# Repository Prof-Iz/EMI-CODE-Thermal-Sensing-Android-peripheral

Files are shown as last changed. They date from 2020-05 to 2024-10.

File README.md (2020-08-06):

# DISCLAIMER | Referencing
This is a work in progress!! Some code may have errors and is purely for my own personal tracking. Eventually if the code works and you are able to use it, by all means please do ;) but remember to **reference my code** to *avoid **plagiarism** issues*<br>
***Ibrahim Izdhan**, 1001852671, UCSI University, Electrical and Electronics Engineering*<br><br>
# EMI CODE Thermal Sensing Android peripheral
 Code repository for EMI Project May Sem Y2 Engineering<br>

Repository contains 4 folders
<ol>Android Code</ol>
<ol>Arduino Code</ol>
<ol>CAD Files</ol>
<ol>PCB Gerber Files</ol>

## Arduino Code
The project in question requires the Arduino to take in data from 2 sensor modules - a thermal sensing module and an ALS distance measuring module. Code would collect the data and then process it before passing data through connected serial to an accompanyng Android device. <br>

### Specifics of Data Processing on the Arduino

#### AP3216 Proximity Sensor (CJMCU - 3216)
The proximity sensor used in the project is a CJMCU IR and Light based proximity sensor. The sensor was programmed using the library by **Wollewad**
https://github.com/wollewald/AP3216_WE and tweaked for single pulse detection mode of proximity following the instructions on his repo. The values received for proximity are compared in a conditional that was calibrated for my specific sensor and if it was within threshold values (**distance of roughly 2 - 4 cm**) from forehead the reading from the thermal sensor is triggered - else the Arduino returns **0** in the serial indicating that the forehead is not at an optimal distance. <br>

#### MLX90614 Thermal Sensor (GY90614)
Once the thermal sensor is triggered, the **getObjectTemperatureC** method is invoked for the mlx object and it returns the temperature of the object. if it is between a validated range the Arduino prints the temperature to 1 dp to the Serial - else 0 is returned to indicate erroneous range for a human.
The code uses the **Adafruit Library for the Module** https://github.com/adafruit/Adafruit-MLX90614-Library to initialise the object and invoke the methods.

## Android Code
The Android app was built with Flutter and coded in Android Studio. The USB portion of the code is based on a flutter port of **felHR85**'s UsbSerial for Android https://github.com/felHR85/UsbSerial - which was found on pub.dev - provided by **Bessem.dev** https://pub.dev/packages/usb_serial. The example code was tweaked to make the phone connect to the first device input into the serial port and only displays the immediate serial data (*it was a list in the example*)

## 3D PRINTING
The CAD files of the Casing design can be found in the **CAD FILES** folder. CAD modelling by *Choy Juen Jet: Electrical and Electronics Engineering, **UCSI University***

## PCB Gerber Files
The files containing the schematic of our project's PCB is located inside the **PCB Gerber Files** folder. The PCB was designed by *Low Wai Sing: Electrical and Electronics Engineering, **UCSI University***

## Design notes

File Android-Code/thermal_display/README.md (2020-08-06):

# thermaldisplay

Supporting Android Application for the EMI project

## Warning
The usb serial library that is used proved to have some issues with Arduino Nano devices using the CH340 interface. The serial communication was unable to run in any mode besides the **release** version of the built APK, for the Arduino Nano and some older Arduino Boards. However, for our porject we used the **Seeeduino Xiao** which did not present these errors, despite running at the same settings for a Nano.

The **http** library that is used with this project to send a **GET** request to the Google Sheets Web App did not work properly with the release verson of the app, thus we had to use the Debug version with the larger binary footprint.

## Repositories/Packages Used
The Repositories/Packages that have been used for this project are noted below.
**usb_serial: ^0.2.4**
The package is used to establish serial connection with any connected devices and the android phone.
Documentation: https://pub.dev/packages/usb_serial

**maps_launcher : ^1.2.0**
The package provides a quick method to launch any maps software installed on your android phone with a specific search query.
Documentation: https://pub.dev/packages/maps_launcher

**path_provider : ^1.6.11**
This package provides commonly used locations on the filesystem. Supports iOS, Android, Linux and MacOS. Not all methods are supported on all platforms.
Documentation: https://pub.dev/packages/path_provider

**audioplayers: ^0.15.1**
This package is used in conjunction with path_provider to play audio files to alert the fever status before temperature is read out.
Documentation: https://pub.dev/packages/audioplayers

**flutter_tts: ^1.2.3**
This package is used to convert text (temperature value) into speech, which will be read out in your program.
Documentation: https://pub.dev/packages/flutter_tts

**flutter_barcode_scanner: ^1.0.1**
This package is to scan and return QR codes data before sending it to the GOOGLE SHEETS DATABASE using http.
Documentation: https://pub.dev/packages/flutter_barcode_scanner

**http:**
This package facilitates the GET request to store the data of individuals with a fever into a GOOGLE SHEETS, which is deployed as a Web App.
Documentation: https://pub.dev/packages/http

<br>
## Flow charts
Flow charts of how the data is roughly processed is given in the **FLOWCHARTS** Folder

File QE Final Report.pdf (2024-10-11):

# FINAL REPORT

# PHONE BASED

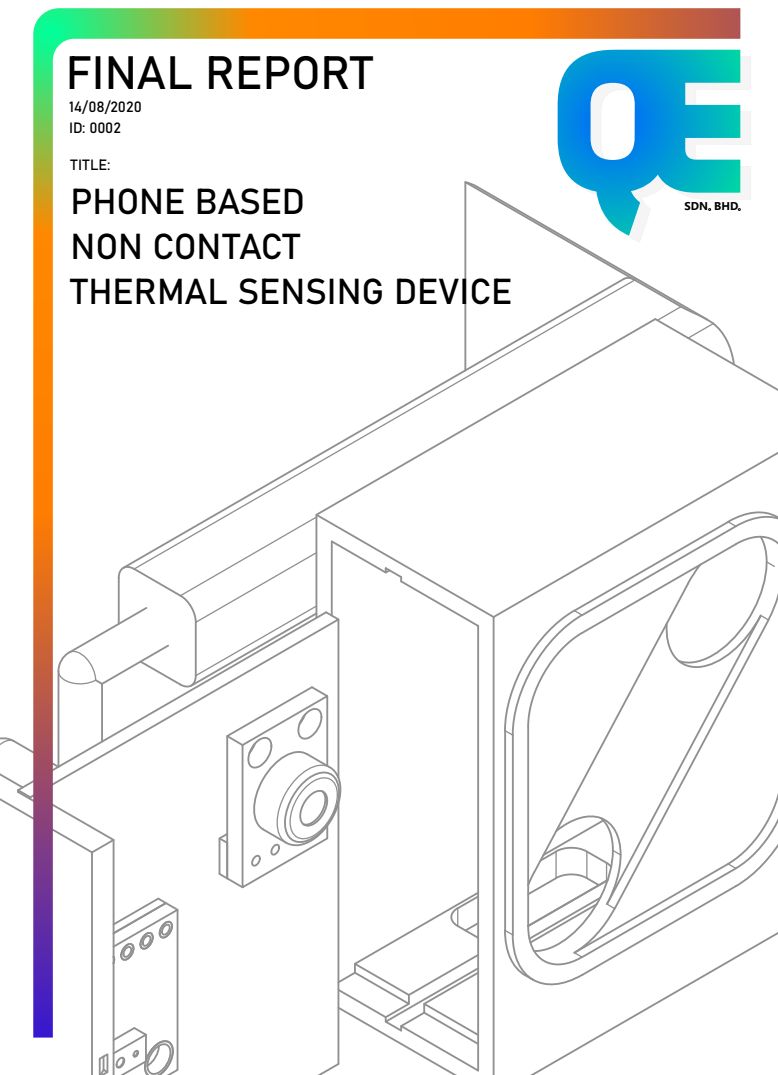
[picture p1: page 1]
SDN. BHD.; TITLE:

NON CONTACT
THERMAL SENSING DEVICE

Non-Contact Phone Thermometer

1

## Contents

2

3

## 1. Introduction

## 1.1. Team Members

Project Engineer: Lim Yee Teng

Software Engineer: Ibrahim Izdhan

CAD Engineer: Choy Jun Juet

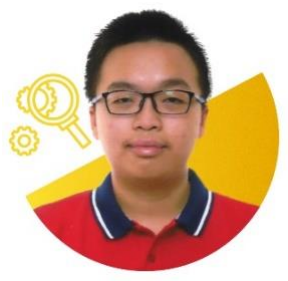
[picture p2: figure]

Test Engineer: Wong Wai Kiat

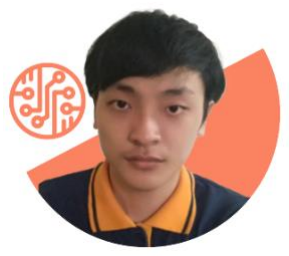
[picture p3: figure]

PCB Engineer: Low Wai Sing

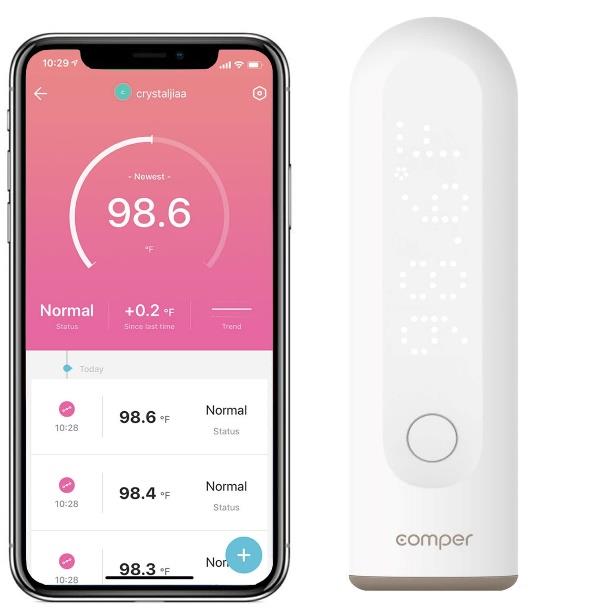
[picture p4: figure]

4

## 1.2. Market Research / Existing Product

The need for thermal screening devices has increased in demand in the wake of the recent Covid-19

pandemic due to its ability to aid frontline workers and governments in determining early signs of infection at

entry screening points [1]. The need for effective thermal monitoring solution has caused an untimely gap in

the supply and demand of conventional devices to achieve this solution – either causing existing solutions to

become unable to deliver or causing spike in prices [2].

One of the market similar smartphone based non-contact thermometers is the thermometer produced by

‘Comper’. Its application is likely used in the medical field. Its measurement method is through infrared ray to

measure the body temperature of people by pointing their forehead. It can be connected to the phone through

Bluetooth to show the value of temperature on the phone. Its temperature range is between 32 oC (89.6 oF)

and 43 oC (109.4 oF). The Comper Smart Infrared Thermometer is designed to read the body temperature

as easy as possible. Besides, their Comper Health App can visualize the body temperature ranges and

trends. The smart infrared thermometer can provide maximum precision with results that are accurate within

0.2 oC and it also can provide results in less than a second. Other than that, Comper Smart Infrared

Thermometer also includes a convenient smart app with features like sharable readings and real time

analytics, and it also supports an unlimited number of users. The thermometer can automatically record all

the temperature and save them to the app for tracking purposes.

Figure 1 Similar Existing Product - Comper Thermal Screening Device [3]

5

## 1.3. Problem Statement

The increase in Covid-19 cases across the country has sparked a need for proper, easily accessible and

cheap screening procedures to be developed in order to accommodate the rising demand for such devices

in places of high traffic. Such a device should be able to screen for fevers, which is a common symptom of

Covid-19, without implicating the persons using the screening device, via non-contact measurement of body

temperature. The device should be easy to operate and should be powered with a power source that is readily

available for most individuals – with clear indication of remaining power status and ability to recharge.

## 1.4. Objective

To develop a cheap Arduino Based non-contact thermometer that interfaces with the user’s phone to provide

clear and precise (to within an acceptable margin of error) temperature of a person being screened. The

device should be powered by the phone’s serial port as well as provide data to the phone via the port to be

processed and displayed on the phone.

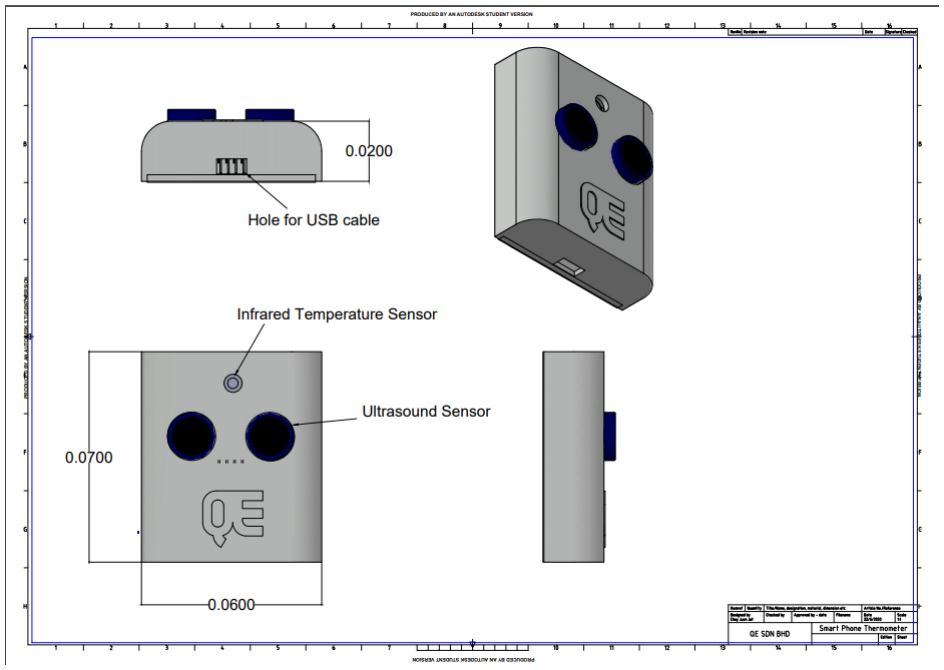
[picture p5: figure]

6

## 2. Methodology

## 2.1. Draft of Product in Proposal

The casing of the design will be

attached to the back of the smart

phone via a simple clamping

mechanism found in most cheap

phone holders – allowing for the

placement of the thermal device to

be agnostic to the dimensions of the

phone. | This | draft | outlook

implements the Ultrasound sensor

to detect proximity of the forehead

from the sensor – the effectiveness

of detection and option to switch to

IR proximity will be tested by test

engineer and the design will be

further revised if necessary.

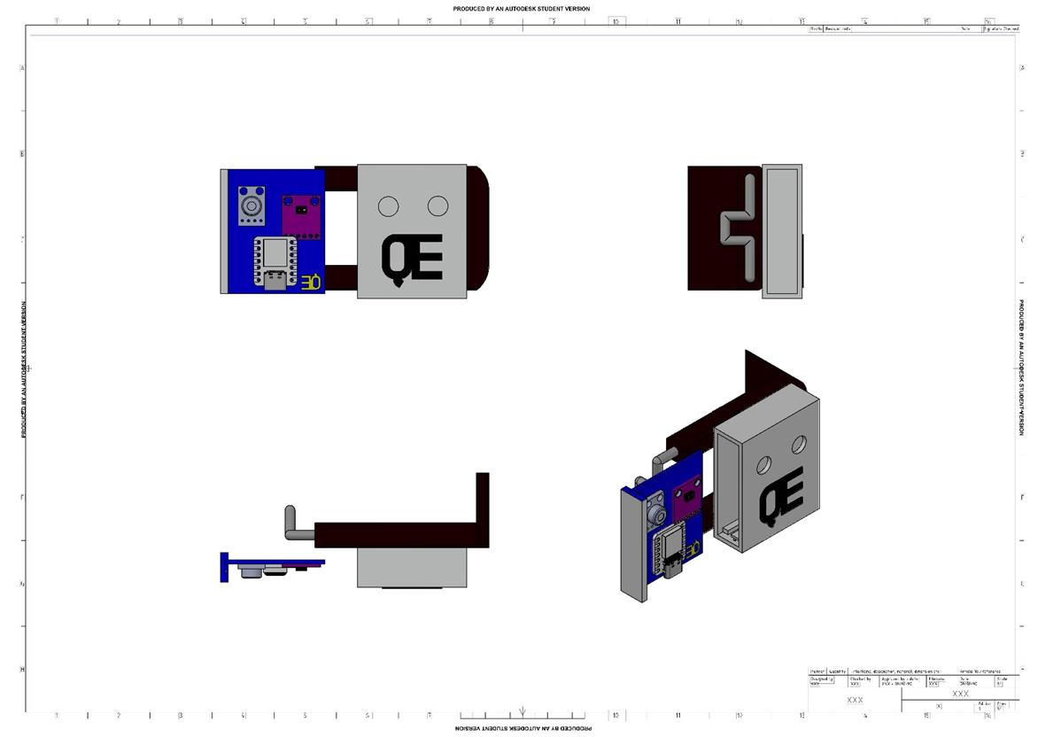
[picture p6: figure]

7

## 2.2. Changed Design due to Hardware Change (1)

The design is based on the PCB

board we first drafted. The PCB

board has 3 important components

which is the Seeeduino Xiao,

temperature | sensor | and | the

proximity sensor. There are 3 holes

designed specifically for these

components. The first one is a

rectangular hole with round edges

at the bottom of the casing which

enables the USB cable connection

with the Seeeduino. The second

and third hole in front of the casing

is for the temperature sensor and

proximity sensor.

Figure 2 Initial Design of Device

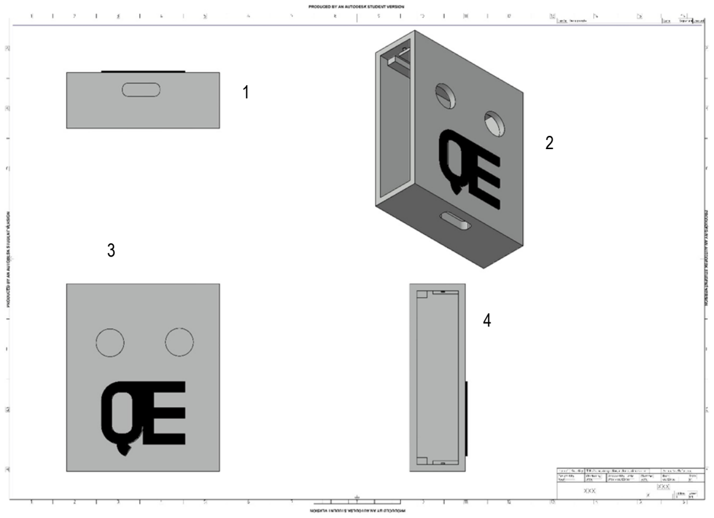
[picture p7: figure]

8

The holes are needed for the temperature

sensor and proximity sensor since the

casing will get in the way of the sensors if

the holes are not there. The holes are

aligned to make the casing tidier. The

logo of our company “QE” is added below

the 2 holes in front of the casing to make

it more aesthetic.

Features:

The hole at the bottom as shown in 1 is

used to connect the USB cable.

The 2 holes in front of the casing as

shown in 3 is for the temperature sensor

and proximity sensor.

The side as shown in 2 and 4 have a

place holder for the PCB board. The PCB

will be attached to the cover at the side

and then slide into the casing.

Figure 3 Initial Design without components nor attached support

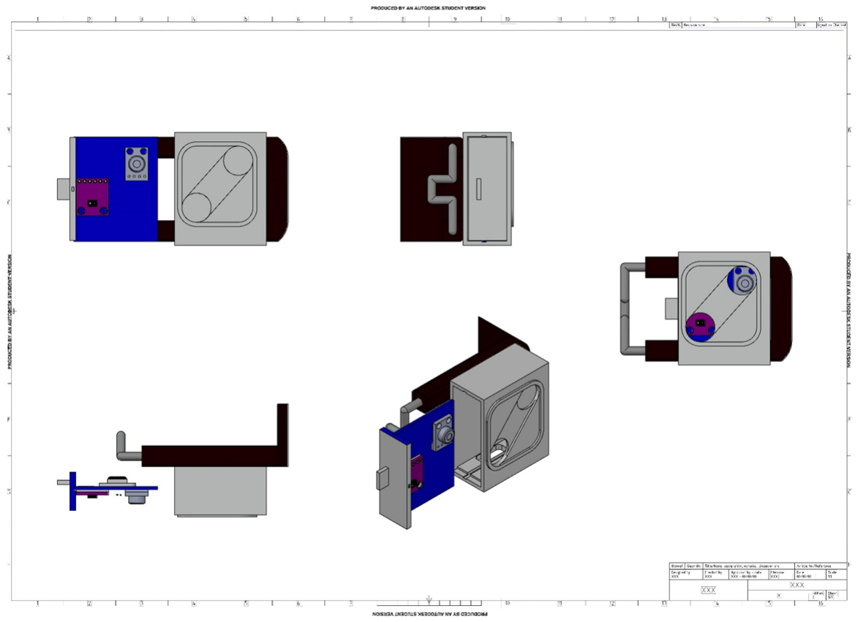
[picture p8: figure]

9

## 2.3. Final Casing Design after Design Restrictions

When we solder the components onto the

PCB, we had some problems with the

placement of the components. To resolve

the problem, the holes for the

components are moved to their

respective components to make the

device work. The new design is based on

the first design with the sliding PCB

mechanism and holes for sensors. A

locking mechanism is added because the

previous design has a problem with the

slide sliding off when in use. A small

extension piece at the side casing is there

because the side casing couldn’t be open

once the casing is closed. The small

piece at the side making sure the casing

can be opened after that. The round edge

rectangular hole for the USB

Figure 4 Final Casing with Support

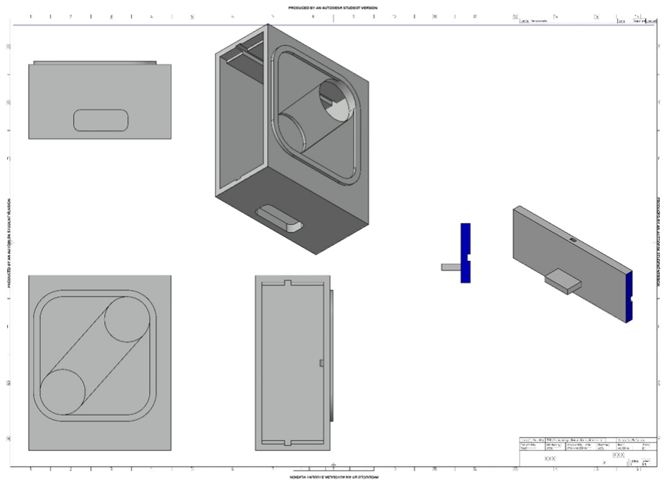
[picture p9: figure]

10

USB didn’t change much except for the

position and the increased size. The

holes for the sensors are also made

bigger to make sure there is no

interference from the casing. Since the

holes are repositioned, the “QE” logo was

removed as there is not enough space for

it. To replace the logo design, a bridge

like structure is made between the holes

where it makes the holes look like its

connected. There is also a square with

round edges around the holes to make it

look tidy rather than holes randomly

placed on the casing.

Features different with second draft:

Hole placement changed to reflect the

PCB.

Side Mounted wall thinner to allow easier

insertion of PCB into case.

Figure 5 Final Casing Design without supports and PCB

11

## 2.4. Proposed Hardware

Arduino Nano | Serve as the Microcontroller to receive data from the thermal sensor (via I2C) as
| well as the ultrasound sensor (via digital pins) and send the data through serial to
| the connected android device. The Arduino will route power supplied to it by the
| phone through its 5V (out) pin to supply power to the attached sensors as well. Any
| intermediate data processing to be done before transmission of data to the phone
| will also be done on the Arduino
MLX90614 Thermal Sensor (GY90614) | The thermal sensor (PCB module) used to detect temperature values. The libraries
| of the sensor are provided by the manufacturer and thus can be used to detect
| temperature at 2- 5 cm with minute manual tuning required in software.
HC-SR04 Ultrasound Sensor Module | The Ultra sound sensor will be used to ensure that the distance from the
| temperature sensor to the forehead of the individual is within the effective range of
| 2 – 5 cm. Processing of distance done within Arduino

## 2.5. Changed Hardware from Proposal Stage

Seeeduino Xiao | Replaces the Arduino Nano as it has a smaller from factor. It is still coded in Arduino
| thus poses no additional development requirements.
AP3216 Proximity Sensor (CJMCU - 3216) | Replaces the HC-SR04 as it is more compact and due to the sequential nature of
| both reading distance and taking temperature (by the temperature sensor), no
| interference is expected due to delay inserted in software.

12

## 2.6. Proposed Software

CAD DESIGN | The proposed software for CAD design of the casing of the non-contact thermometer is Auto CAD due to the simple nature of the casing design (no mechanically moving components) as well as prior experience with Auto CAD
PCB DESIGN | The proposed software for PCB Design is EasyEDA due to its simple UI and low learning curve. In addition, the said software supports placing order for custom made PCBs through vendors such as JLC PCB (easy output to Gerber file)
App Development (Android) | The proposed software for developing the phone interface to be used with the non- contact thermometer is Android Studio as it will allow the creation of a highly customizable and free (in terms of subscriptions to be paid for the use of said app or specific allowances required for the design of the app) android application that can be provided free of charge alongside the device. Android Studio allows for virtual debugging, though this will not be as useful for a serial-based application, the layout can be tested before being uploaded onto a real test device
Arduino Coding | The base Arduino IDE is the only available method and will be used to code the Arduino Nano that will be used in the non-contact thermometer

## 2.7. Changed Software from Proposal Stage

App Development | Production switched from JAVA to using the Flutter framework by google, which implements the use of the DART programming language.
3D Printing | Since it was decided to 3D print the casing for the thermal sensing device, Ultimaker Cura was used as it is a free and eeasy to use 3D printing/splicing solution

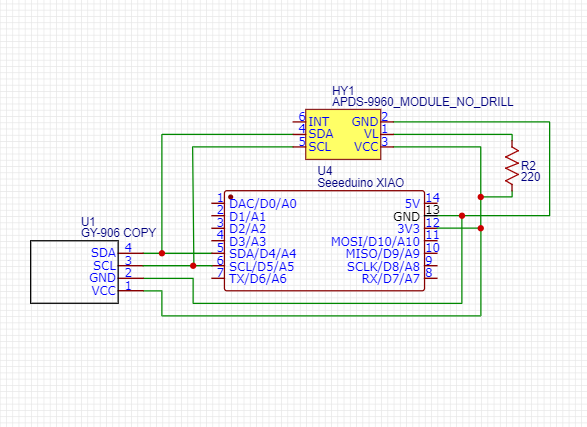
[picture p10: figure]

13

## 3. Circuit Design

Figure 6 Circuit Schematic of the project

The operational voltage of both the GY-906 and the AP3216 Proximity Sensor is between 3.3 – 5 V, thus the

lower option was preferred for safety of the components. Both of these sensors are designed to communicate

using the I²C protocol and as such have been connected in a manner that their SCL (Clock) and their SDA

(Data) are interconnected with each other. A 220-ohm resistor is used to bias the IR blasting mechanism in

the AP3216 Proximity Sensor. All grounds in this system are common (Seeeduino) and are interconnected

together.

The circuit as seen in Figure 6 was designed in EasyEDA to streamline the PCB manufacturing process later

on. The schematic connections were chosen from the EDA library and then compared to ensure that the

models were the same. As noticeable in Figure 6, the model for AP3216 Proximity Sensor, is used

interchangeably with the APDS9960 as the connection schematic is the same.

14

## 4. Breadboard Testing

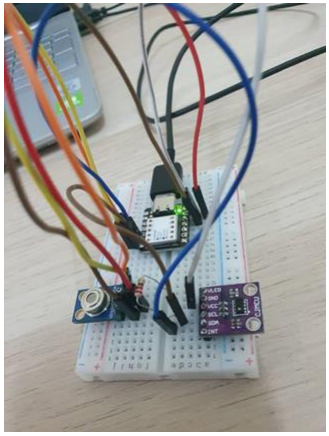
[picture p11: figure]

Figure 7 Breadboard placement of components

Before doing the breadboard testing, the MLX90614

thermal sensor and proximity sensor were soldered

with the pins provided to ensure that they have good

connection with the breadboard while testing on it –

so that the signal passed using I2C is delivered

properly.

Next, the code written by software engineer was

transmitted to the Seeeduino XIAO for the test

engineer to test the functionality of thermal sensor

and proximity sensor individually using the standard

test code provided by the manufacturer. Afterwards,

the test engineer placed all the components on the

breadboard based on the circuit designed by the

PCB engineer as shown in Figure 7 and check

whether the components were connected correctly

to prevent short circuit. In our first testing on

breadboard, we did not get the results that we

wanted. Then, after further testing, the test

engineer figures out that it is the problem of

breadboard and replaced it with another new

breadboard. After replacing the breadboard, we

observe the results that we wanted. This means that

all the components are in good condition and the

circuit connection is correct. Afterwards, the tested

components were handed to the software engineer

for further calibration and tuning.

## 5. PCB Design

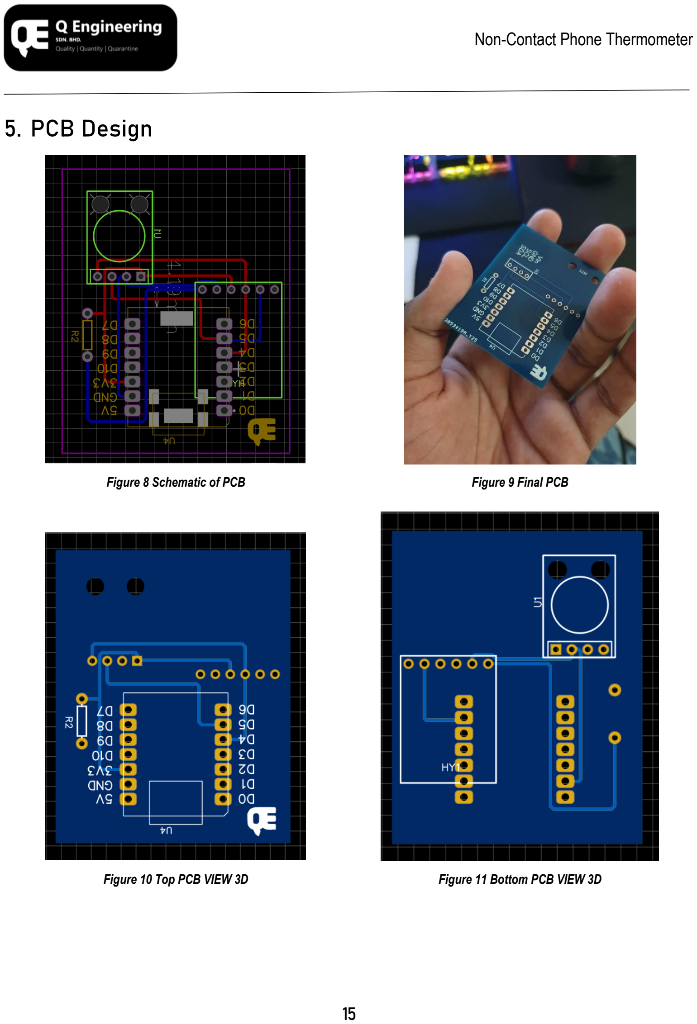
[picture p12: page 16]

15

Figure 8 Schematic of PCB | Figure 9 Final PCB
Figure 10 Top PCB VIEW 3D | Figure 11 Bottom PCB VIEW 3D

16

PROCEDURE:

1. After designing the circuit, converted it to PCB and the footprint of the electronic parts were checked
2. Set the PCB board outline as diameter equal to (50mm*40mm).
3. Dragged all the electronic parts at the default position inside the PCB board.
4. Changed the proximity sensor and infrared thermometer sensor from top silk layer to bottom silk

layer.

5. Set the width of trace as 20 mil at the setting and start connecting the components. Changed to trace

to bottom layer when the trace overlaps each other.

6. Selected image at ‘PCB tools’ to insert our company logo at top silk layer of our PCB design.
7. After finishing and saving the PCB design, click the ‘Design Manager’ to check for any errors
8. Gerber file for our PCB design was then generated once everything was set up correctly and ordered

our PCB through JLCPCB.

When converting the circuit design to PCB, ensure all the components have the correct footprint with the real

components that are used. For the connection of traces in the PCB, avoid using 90-degree trace angles, opt

for 45 degrees as the edge of the 90 degrees tracks will be etched smaller than the trace width set by designer

or those tracks will not be fully etched and might lead to a short circuit. For the ideal PCB design, the turning

point of each track should be curved but due to limitation, we used the smaller 45 degrees gaps. Next, enough

space should be left between all the tracks and the components so as to avoid overlapping as the PCB

manufacturing process might not be entirely precise. As we know, the higher the resistance, the lower the

power dissipated as the resistance is inversely proportional with current, and current powered by two is

directly proportional to power consumption. Last but not least, PCB design should always be printed on a

blank paper to double check whether the footprint is exactly similar to the parts that are being used to ensure

that the specific component matches with the footprint in EasyEDA.

17

## 6. Software Development

## 6.1. Android App Draft Plan

Illustrated below is the draft plan of the layouts (views¹
) that comprise the accompanying android application to be used with the thermal sensing

device. Design is subject to change based on further debugging or usage testing.

View when serial device is

properly transmitting data

and temperature is within

accepted range

View when serial device

is disconnected or there

is an issue with data

received

View when the data

received indicates that the

forehead is too far from

the optimal range

View when the

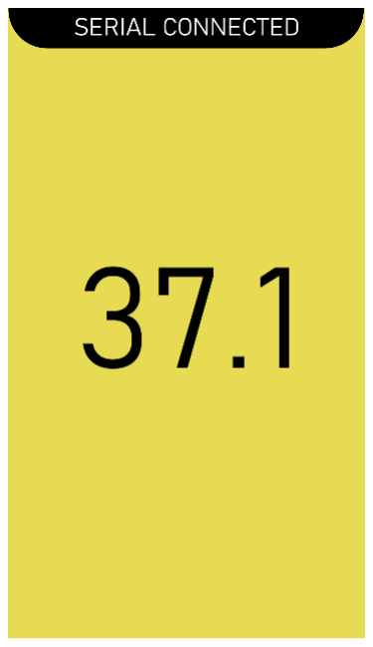
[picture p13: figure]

temperature is close to

the upper threshold for a

fever

View when fever detected

– button to view hospitals

on maps (google

extension)

1 Android applications are comprised of “views” that contain fundamental elements such as images, text and other placeholders – whose attributes can be updated via functions

18

## 6.2. Android App Finalized Widgets

The draft design of our application was designed with the software intended to be coded in JAVA. However, during production the team decided that

Flutter would be a more interactive solution to designing the app hence the design was slightly altered while maintaining key design features from the

previous design and implementing additional features which will be discussed in detail in the following sections.

Initial Startup Screen of

Application, Seeeduino

not detected thus showing

Disconnected

Status shows connected

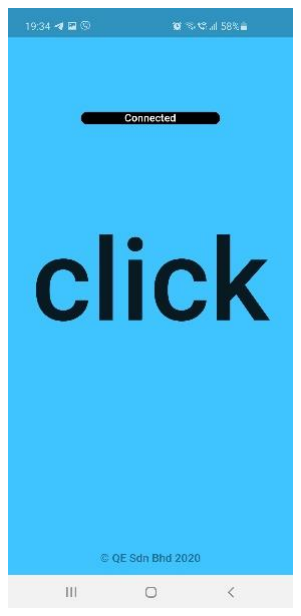
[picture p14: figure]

but the request to get

temperature reading not

set

Screen that shows

temperature received if it

is within a non-fever

region. Color changes.

When fever is detected a

button appears with more

options as seen in the

bottom right.

More options screen once

fever detected, to scan QR

and upload details to

server, call Hospital

19

## 6.3. Main Screens in Detail

1 – The Serial Connection Status between the

Seeeduino and the Phone. It will update the

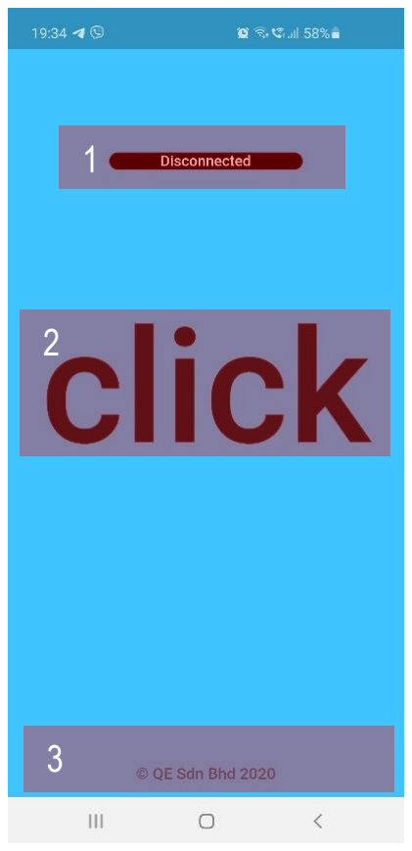
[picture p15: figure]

message | when | the | Seeeduino | is

connected/disconnected and will also update if the

Android program detects if there are any problems

with the connection, such that a device is connected

but data is unable to send properly.

2 – The entire region serves as a button which

initiates the requestTemperature() function, which

will prompt the Seeeduino to send data over to the

phone.

3 – If the user clicks this region they will be taken to

a widget(page in Flutter) where the information of

the compay is displayed and they may contact us

via Instagram.

These 3 Regions are present in all screens

(besides the QR scanning page and company info

page)– and serve the same function.

20

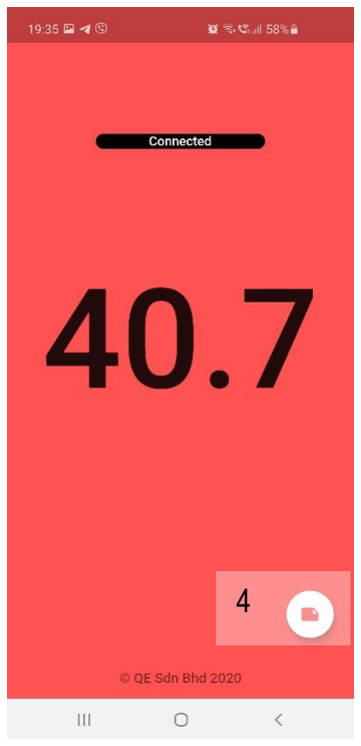
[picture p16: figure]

4 – Once the average temperature taken over 3

successful consecutive readings average out to be

greater than the standard fever temperature (37.5o

C), the region is made active. Clicking on the button

in this region will direct the users to a widget (screen

below) where they will be able to deal with such

cases more effectively.

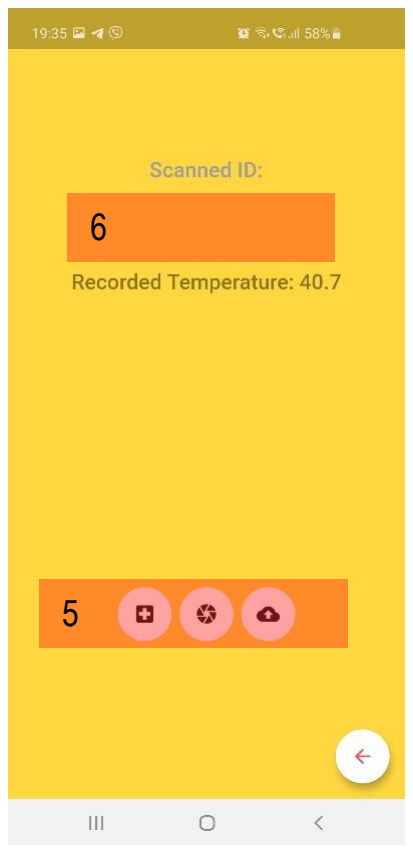
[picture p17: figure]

5 – This region consists of 3 buttons with 3 distinct

functions. From the left, the button opens up any

mapping software installed on your device such as

google maps and automatically searches for

hospitals nearby. The second button, when pressed

opens a scanning window where the user can scan

the ID of the affected Employee. This data is

automatically displayed on (6) so that they may

double check the reading. The last button in this row

automatically updates the data of the ID, as well as

the temperature recorded to a Google Sheets

database that the company HR may keep track of –

no manual entry required.

21

## 6.4. Installation of IDEs

ARDUINO IDE

The Arduino IDE can be installed through the windows store or following instructions located at the

official Arduino Website https://www.arduino.cc/en/main/software. The Seeeduino board used

should be enabled in the IDE by following the instructions found at the official Seeeduino website

https://wiki.seeedstudio.com/Seeed_Arduino_Boards/

ANDROID STUDIO (FLUTTER)

Android Studio can be installed using the link https://developer.android.com/studio/install. Once the

IDE has been installed, enable Flutter development on Android Studio using the instructions on the

Flutter website https://flutter.dev/docs/get-started/editor.

In your Flutter project, inside android > app > build.gradle set the minSdkVersion 21 so that the QR

code scanning features work.

## 6.5. Arduino Dependencies

The project in question requires the Arduino to take in data from 2 sensor modules - a thermal sensing module

and an ALS distance measuring module. Code would collect the data and then process it before passing

data through connected serial to an accompanying Android device.

AP3216 Proximity Sensor (CJMCU - 3216)

The proximity sensor used in the project is a CJMCU IR and Light-based proximity sensor. The

sensor was programmed using the library by Wollewad, which can be accessed

at https://github.com/wollewald/AP3216_WE , and tweaked for single pulse detection mode of

proximity following the instructions on his repo. The values received for proximity are compared in a

conditional that was calibrated for our specific sensor and if it was within threshold values (distance

22

of roughly 2 - 4 cm) from forehead the reading from the thermal sensor is triggered - else the

Arduino returns 0 in the serial indicating that the forehead is not at an optimal distance.

MLX90614 Thermal Sensor (GY90614)

Once the thermal sensor is triggered, the getObjectTemperatureC method is invoked for the mlx

object and it returns the temperature of the object. if it is between a validated range the Arduino prints

the temperature to 1 dp to the Serial - else 0 is returned to indicate erroneous range for a human.

The code uses the Adafruit Library for the Module https://github.com/adafruit/Adafruit-MLX90614-

Library (https://github.com/adafruit/Adafruit-MLX90614-Library) to initialize the object and invoke the methods.

## 6.6. Flutter Dependencies

The dependencies to be placed in the pubspec.yaml file in your Flutter project are bolded below with a short

description of what each package does.

usb_serial: ^0.2.4

The package is used to establish serial connection with any connected devices and the android

phone.

Documentation: https://pub.dev/packages/usb_serial

maps_launcher : ^1.2.0

The package provides a quick method to launch any maps software installed on your android phone

with a specific search query.

Documentation: https://pub.dev/packages/maps_launcher

path_provider : ^1.6.11

This package provides commonly used locations on the filesystem. Supports iOS, Android, Linux

and MacOS. Not all methods are supported on all platforms.

Documentation: https://pub.dev/packages/path_provider

23

audioplayers: ^0.15.1

This package is used in conjunction with path_provider to play audio files to alert the fever status

before temperature is read out.

Documentation: https://pub.dev/packages/audioplayers

flutter_tts: ^1.2.3

This package is used to convert text (temperature value) into speech, which will be read out in your

program.

Documentation: https://pub.dev/packages/flutter_tts

flutter_barcode_scanner: ^1.0.1

This package is to scan and return QR codes data before sending it to the GOOGLE SHEETS

DATABASE using http.

Documentation: https://pub.dev/packages/flutter_barcode_scanner

http:

This package facilitates the GET request to store the data of individuals with a fever into a GOOGLE

SHEETS, which is deployed as a Web App.

Documentation: https://pub.dev/packages/http

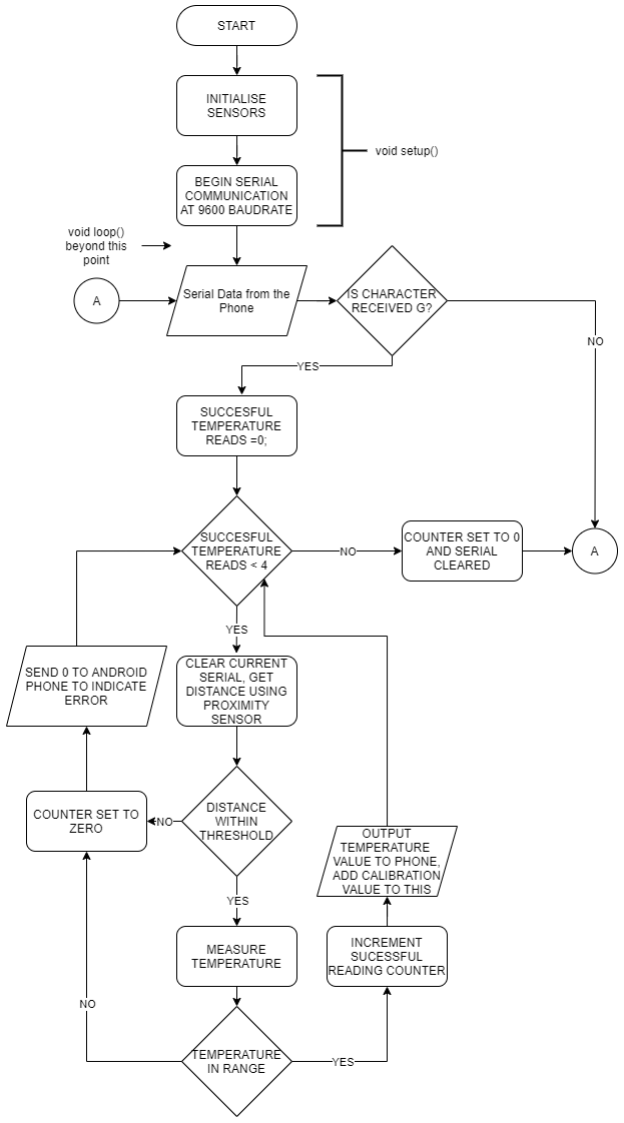
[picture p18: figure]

24

## 6.7. Flow Chart Seeeduino (Arduino)

Figure 12 Flow Chart of Arduino Code

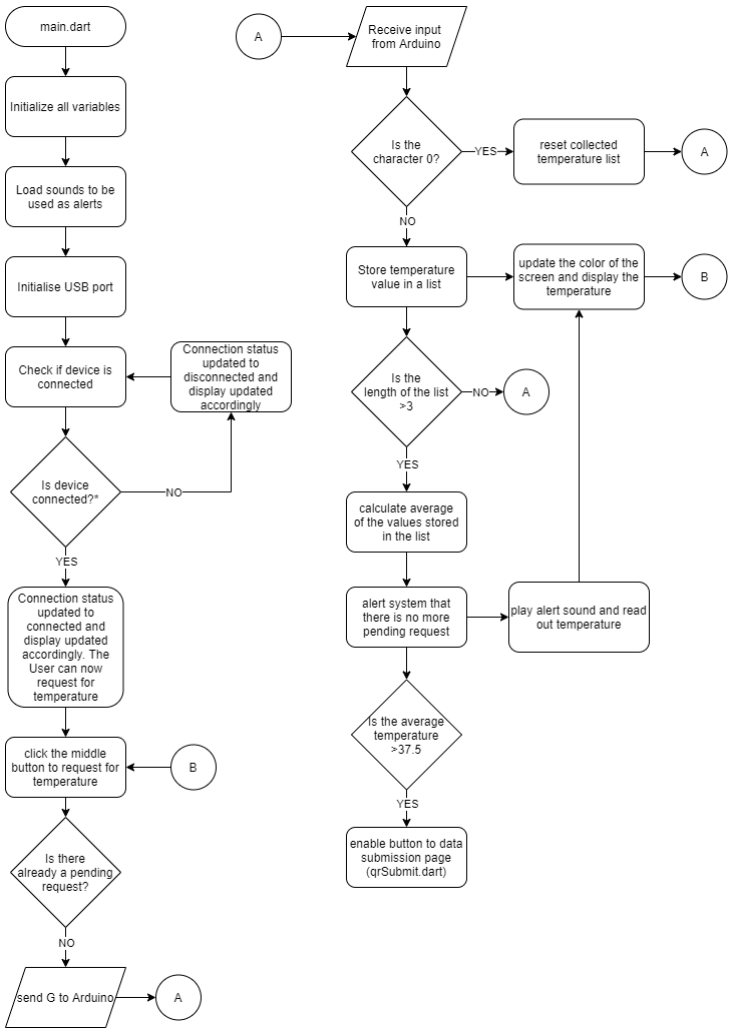
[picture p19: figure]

25

## 6.8. Flow Chart Android App

Some actions are always running in the background hence it is indicated with a *.

Figure 13 Flow chart of home screen

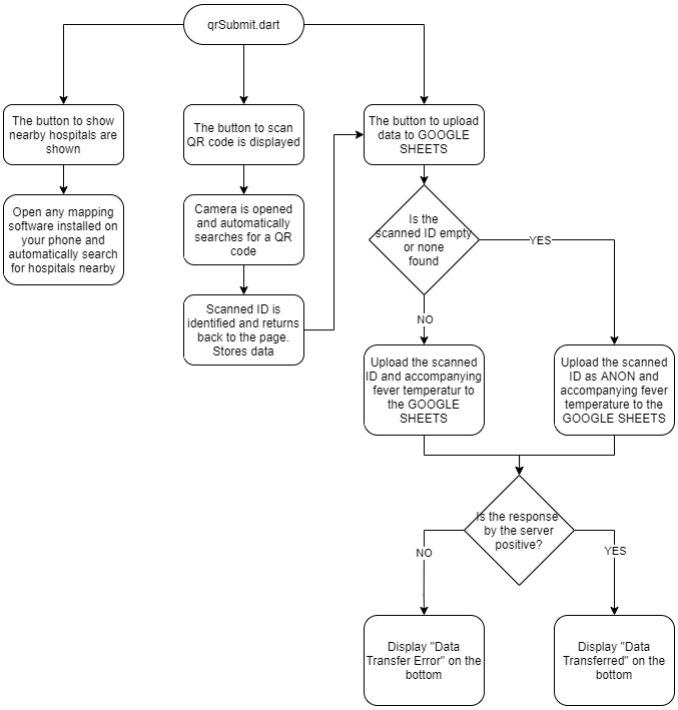
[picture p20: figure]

26

Figure 14 Flow Chart of Fever response page

27

## 6.9. Explanation of Key Functions (Arduino)

getProximityArduino() This function when called first sets the proximity sensor to a single pulse

mode. Then after a delay of roughly 0.6 seconds, it measures the distance

using the proximity sensor. If the retrieved distance value is between a

range of 1000 of 40 (which is roughly between 2-4 cm), the function goes

to getTemperature(). If the distance is greater the counter of successful

readings and sends 0 to the Android phone as mentioned in Figure 12.

getTemperature() Read the temperature and store it. Checks if temperature is between 10

and 50 degree Celsius and if its is out of this range, resets the counter of

successful readings and sends 0 to the Android phone as mentioned in

Figure 12. If it is within the accepted range the temperature that was

recorded to the Android Phone.

## 6.10. Explanation of Key Functions (Android)

main.dart – HomeScreen

_speak() This function makes your code read out the given text. Which in our

case, includes the temperature displayed on the Screen (Final

Average Temperature).

playSoundFever() and

playSoundNormal()

These Functions play a warning sound (playSoundFever()) when

the temperature of the user averages out to be more than 37.5, or

an okay sound effect (playSoundNormal()) when the temperature is

lower than 37.5. These functions are triggered whenever the final

average temperature is calculated.

28

_loadSounds() Prepare the sounds that are used in the above portion.

_connectTo(device) This function connects to the device passed into it and sets the app

so that it automatically updates the status of the connection and

once the data is received from the Arduino, it automatically updates

the display in the middle of the app.

_getPorts() This function runs when a device is connected into the Android

phone, and checks whether it can establish a communication to the

device using the above function.

requestTemperature() This function sends a letter G to the Arduino triggering the Arduino

to start its reading process. This function is programmed in a way

so that it does not allow multiple requests – one request sent to the

Arduino at a time.

updateColorsAndOpacity() This function is run each time the phone receives a temperature

reading from the Arduino. It tries and takes 3 successful consecutive

readings from the Arduino and calculates the average. If this

calculation is interrupted by the 0 message from the Arduino, the

phone displays FAR to indicate that the value is false and repeats

the average procedure from scratch again. Once the average

temperature is calculated, appropriate sounds are played and the

color of the background changes. If a fever is detected, it allows the

user to navigate to another page (by showing a button) that would

allow them to store the temperature in a database, or search for

nearby medical assistance.

29

qrSubmit.dart – The screen that pops Up after you click the button to log temperature when fever

is detected

scanEmployeeID() This function opens the camera and allows you to scan QR codes.

Returns the QR code value and is displayed on the screen.

submitData() This function when invoked submits the data to the GOOGLE

SHEETS web app that will be created upon the request of the

company. For now it sends the scanned ID and the temperature that

was recorded to the web app in the URL inside the function.

_showSnackbar(String message) This function shows a little notification on the bottom of the app with

whatever message is passed into it. It is used inside submitData()

to show the status of the data upload.

## 7. Source Code and All Accompanying files

The source code of the project can be found at our software engineer’s GitHub account and is distributed

under the MIT License of fair usage. https://github.com/Prof-Iz/EMI-CODE-Thermal-Sensing-Android-

peripheral. (https://github.com/Prof-Iz/EMI-CODE-Thermal-Sensing-Android-peripheral) This source code further explains in detail of how the code works through comments. The GitHub

repository also contains the STL files of the CAD model for 3d printing as well as the Gerber files of the PCB.

If anyone wished to reproduce our results they may do so using the resources available at this repository.

## 8. Warning

Due to the nature of some dependencies having issues in Flutter, the app was built and is distributed in

Debug mode. It offers the same functionality as the release version of the app with the exception of the file

size being larger, though this does not pose much of a challenge as the max size is still approximately 50MB.

Since the components need to be soldered using a soldering iron onto the PCB, care must be taken to ensure

that the thermal sensor is not exposed to high heat during the soldering process.

## 9. Finished casing and Product

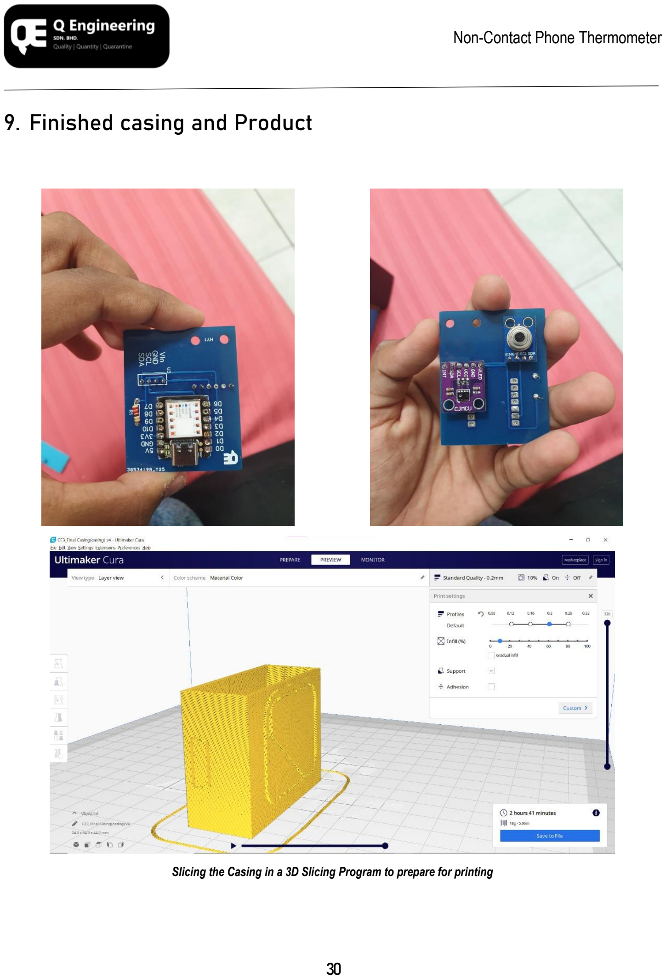
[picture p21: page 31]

30

Slicing the Casing in a 3D Slicing Program to prepare for printing

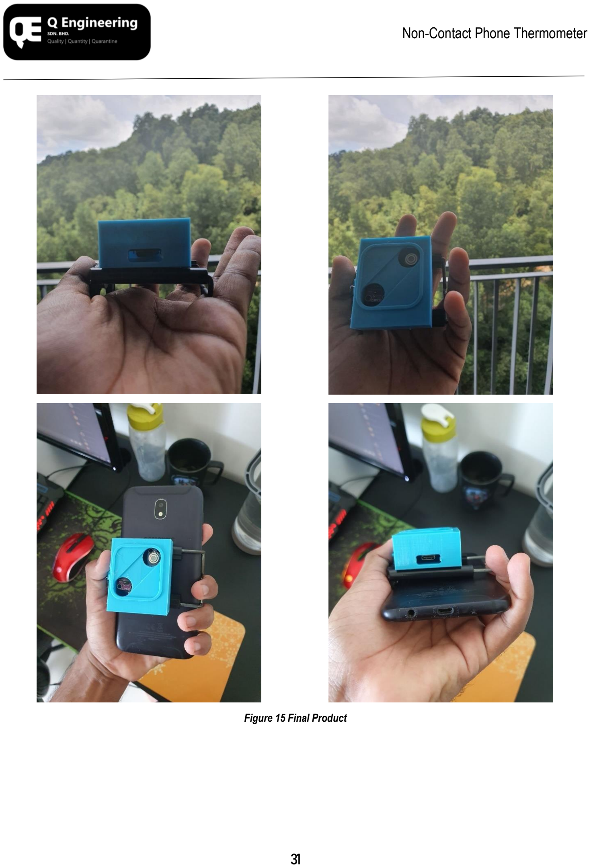
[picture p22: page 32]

31

Figure 15 Final Product

32

## 10.Costing

## 10.1. Projected Costing

Item | Approx. Unit Price | Quantity | Subtotal
MLX9061 GY-906 Module | MYR 100.00² | 1 | MYR 100.00
Arduino Uno | MYR 14.00 | 1 | MYR 14.00
Ultrasound Sensor Module HC-SR04 | MYR 5.00 | 1 | MYR 5.00
Casing | MYR 10.00 | 1 | MYR 10.00
PCB Manufacturing | MYR 20.00³ | 5 4 | MYR 20.00
| | Total | MYR 149.00

## 10.2. Actual Costing

Item | Approx. Unit Price | Quantity | Subtotal
MLX9061 GY-906 Module | MYR 132.00 | 1 | MYR 132.00
Seeeduino Xiao | MYR 34.90 | 1 | MYR 34.90
AP3216 Proximity Sensor | MYR 12.00 | 1 | MYR 12.00
Casing (3D print)⁵ | MYR 0.90 | 1 | MYR 0.90
PCB Manufacturing + Shipping | MYR 28.37 | 5 | MYR 28.37
| | Total | MYR 208.17

The high price in making of the functional prototype is mainly attributed to the inflated price of the MLX9061

GY-906 Module due to shortages in supply and increased demand due to the onset of COVID -19. This

sensor tends to retail as low as MYR 20 s thus we anticipate that with the increase of supply and decrease

2 Sensor price currently high due to increased demand during Covid-19 Peak season
3 Rough conversion from USD to MYR and approximation of shipping fees for 5 PCB
4 PCB printing service provides 5 PCBs as standard package – only one used per thermal device 5 Assuming 1kg reel at RM50

33

in demand stabilizes the price back to its pre COVID-19 levels, the price of the product will become more

affordable.

## 11. Special Thanks

TMOM Sdn Bhd and QE Sdn Bhd worked closely and shared development ideas regarding the software thus

we would like to express our gratitude to them.

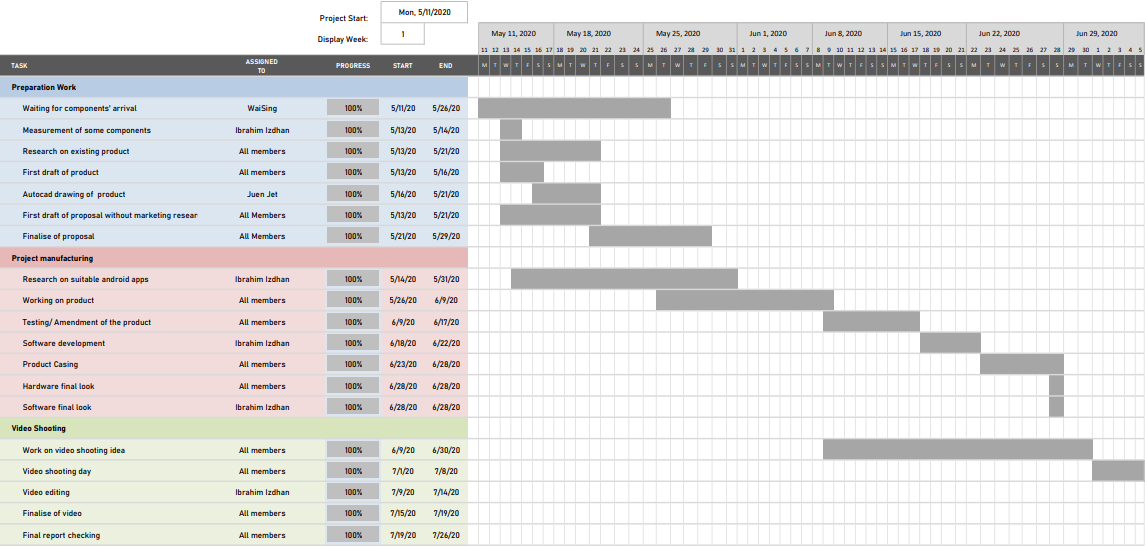
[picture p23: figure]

34

## 12.Project Schedule

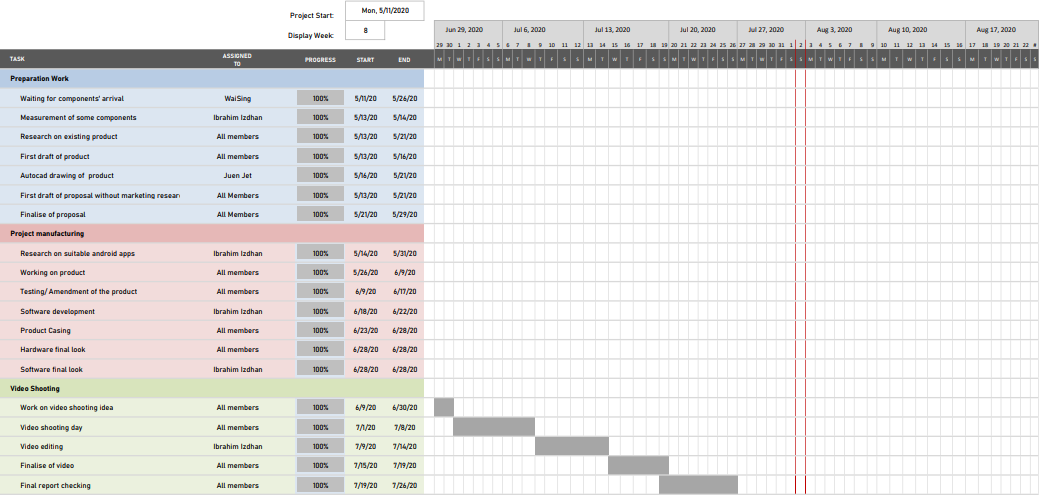
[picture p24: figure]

35

36

## 13.References

[1] WHO, "Updated WHO advice for international traffic in relation to the outbreak of the novel coronavirus

2019-nCoV," 2020. [Online]. Available: https://www.who.int/news-room/articles-detail/updated-who-

advice-for-international-traffic-in-relation-to-the-outbreak-of-the-novel-coronavirus-2019-ncov-24-jan/.

[2] J. Bogaisky, "Tech That Scans People For Fever In Big Demand Amid Coronavirus Crisis, Boosting
Wuhan | Company," | Forbes, | 2020. | [Online]. | Available:

https://www.forbes.com/sites/jeremybogaisky/2020/02/10/we-are-running-as-fast-as-we-can-

coronavirus-sparks-surge-in-demand-for-infrared-fever-detection-equipment/#191e675d60c9.

[3] Medical Expo, "MEDICAL THERMOMETER / INFRARED / NON-CONTACT / FOREHEAD," [Online].

[Accessed 2020].

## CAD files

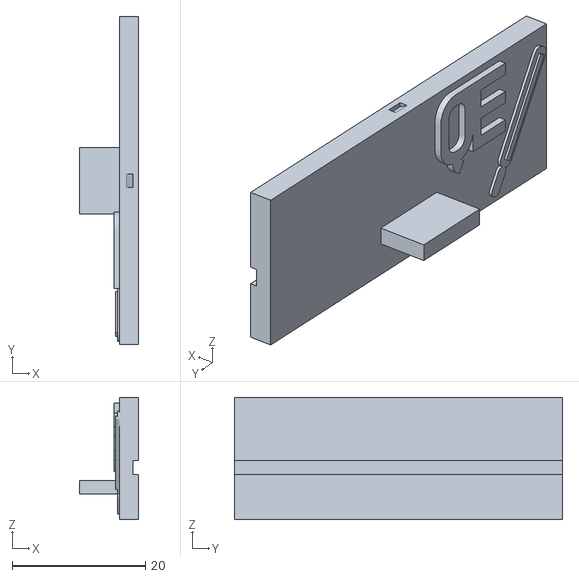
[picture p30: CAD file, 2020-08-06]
CAD-FILES/Final Casing(Side) v3.stl
8.80 x 49.3 x 18.4

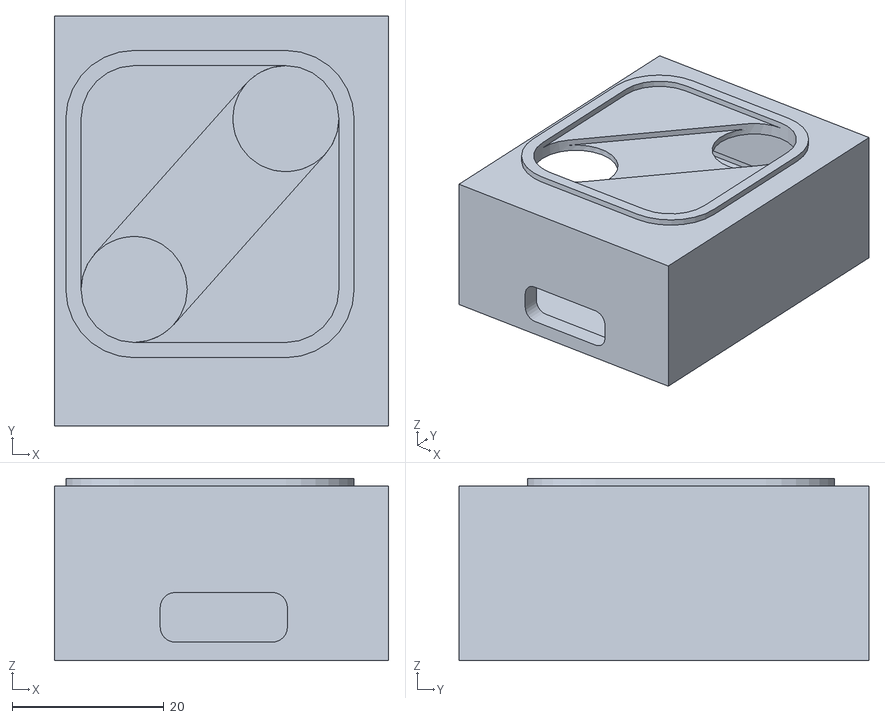
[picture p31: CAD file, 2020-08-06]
CAD-FILES/Final Casing(casing) v4.stl
44.0 x 54.0 x 24.0

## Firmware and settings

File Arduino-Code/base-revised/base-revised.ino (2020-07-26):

#include <Wire.h>
#include <Adafruit_MLX90614.h> //download header file
#include <AP3216_WE.h>         //download header file

// Declaration of functions
void getProximityArduino();
void getTemperatureC();

Adafruit_MLX90614 mlx = Adafruit_MLX90614(); //Temperature detection object

AP3216_WE prox = AP3216_WE(); // proximity detection object
int proximity_delay = 600;    //600ms delay for proximity sensor < to be tested

int count = 0; // counter to track 4 consecutive correct measurements

void setup()
{
    Serial.begin(9600);
    Wire.begin();
    mlx.begin();

    // Proximity Sensor Calibration
    prox.init();
    prox.setMode(ALS_PS_ONCE);
    prox.setLuxRange(RANGE_20661);
    prox.setPSGain(2);
    delay(proximity_delay); //initial Sensor Calibration

    // --------------------------------------------
}

void loop()
{
    char command = Serial.read();
    if (command == 'G')
    {
            while (count < 4){
            Serial.flush();
            getProximityArduino();
            delay(300); // coordinate with phone app to send 'G' , Delay 500
            // Serial.flush(); commented out for debugging
            }
        
    }
    count = 0; //reset counter value for next time
    Serial.flush(); // check if repeated requests to get temperature are not chained
}

void getProximityArduino()
{
    prox.setMode(ALS_PS_ONCE); //initiating measurement
    delay(proximity_delay);    //check for optimal delay time
    unsigned int proximity = prox.getProximity();
//    Serial.println(proximity); //debugging for calibration

    if ((proximity > 1000) || (proximity < 99)) //calibrate values after testing
    {
        Serial.println("0"); //if out of optimal range return 0
        count = 0; // if erroneous value set to 0;
    }
    else
    {
        getTemperatureC(); // if proximity in optimal range continue to get temperature
    }
}

void getTemperatureC()
{
    float temp = mlx.readObjectTempC();

    if ((temp < 10.0) || (temp > 50.0))
    {
        Serial.println("0"); // if temperature outside validated range return 0
        count = 0; // if erroneous value set to 0
    }
    else
    {
        Serial.println(temp + 3, 1); // if temperature inside validated range return temperature to one dp
        count ++; // increment counter for each successful measurement taken
    }
}

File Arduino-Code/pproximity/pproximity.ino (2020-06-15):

#include <Wire.h>
#include <AP3216_WE.h> 
    
AP3216_WE prox = AP3216_WE(); // proximity detection object
int proximity_delay = 300;

int count = 0;
void getProximityArduino();

void setup(){
  Serial.begin(9600);
  Wire.begin();
  prox.init();
    prox.setMode(ALS_PS_ONCE);
    prox.setLuxRange(RANGE_20661);
    prox.setPSGain(2);
    delay(proximity_delay); //initial Sensor Calibration
}

void loop(){
  if (Serial.available()){
    if (Serial.read() == 'G'){
      while (count <20){
      Serial.flush();
      getProximityArduino();
      count++;
      }
      count =0;
    }
  }
}


void getProximityArduino()
{
    prox.setMode(ALS_PS_ONCE); //initiating measurement
    delay(proximity_delay);    //check for optimal delay time
    unsigned int proximity = prox.getProximity();
    if (proximity> 800){
      Serial.println("Close Enough");
    }
    else{
      Serial.println("Too far");
    }
    }

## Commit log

2020-05-29 intialising Arduino Portion
2020-06-02 Comments and additional files
    [Connection Pins.xlsx]
2020-06-03 switch from ultrasound to proximity sensor
    Switch from ultrasound to Proximty sensor. Method of Data transfer revised / Arduino base-revised has compiled properly. Threshold testing and real world debugging remaining
    [Connection Pins.xlsx]
2020-06-10 Update main.dart
    made code changes to connect to first serial device that is baud rate 9600
2020-06-15 testing proximity sensor seperately
    code file to test proximity sensor seperately
2020-06-16 update of android app - implemented serial w/issues
    the update of the background color of the scaffold and the opacity of the callHospital floating action button is not triggering with the _serialData. Suggest to move the parsing function/code directly inside build method
    [base-revised.ino]
2020-06-22 removed isNumeric causing errors with setState and changed arduino error output to 0 instead of X - process later on phone
    [base-revised.ino]
2020-06-22 Arduino and Android Code fully working
2020-06-29 flush to attempt to prevent multiple clicks
    [base-revised.ino]
2020-08-06 Updated Readme and supporting files
    [Final Casing(Side) v3.stl, Final Casing(casing) v4.stl]
